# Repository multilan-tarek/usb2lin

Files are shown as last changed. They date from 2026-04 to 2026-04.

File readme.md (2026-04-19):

## USB2LIN

This is a 4-channel interface for LIN buses.\
It is using 4 NXP TJA1021 and a MaxLinear XR21V1414IM USB to UART bridge. 

Tested with BMW I/K-Bus, but it should work with any LIN bus.

---

### Gerber Files 
The gerber file is ready for ordering at JLCPCB.

### Parts
The schematic contains LCSC part numbers which can be exported to a BOM.

### Udev rules
This repository contains a udev rules file that maps the UART ports to ```/dev/lin/a@,b@,c@,d@```, matching the boards silkscreen.

---

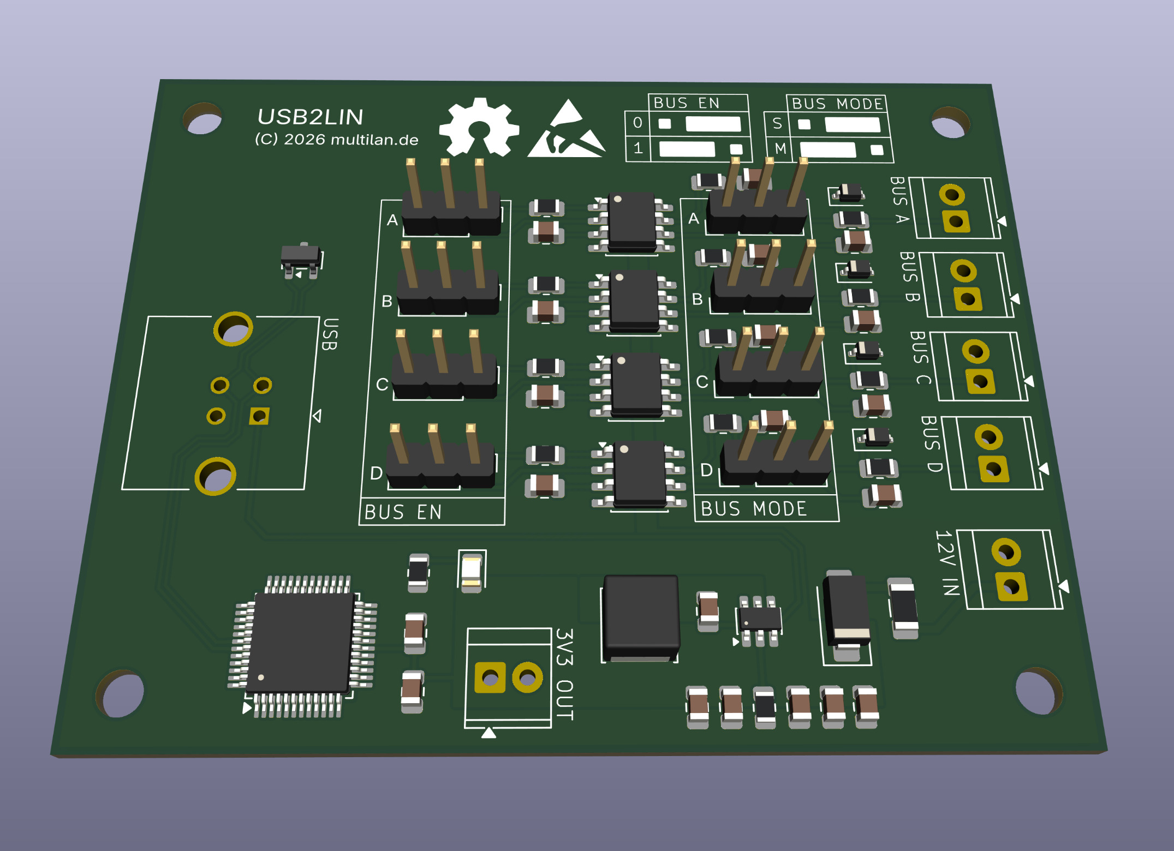
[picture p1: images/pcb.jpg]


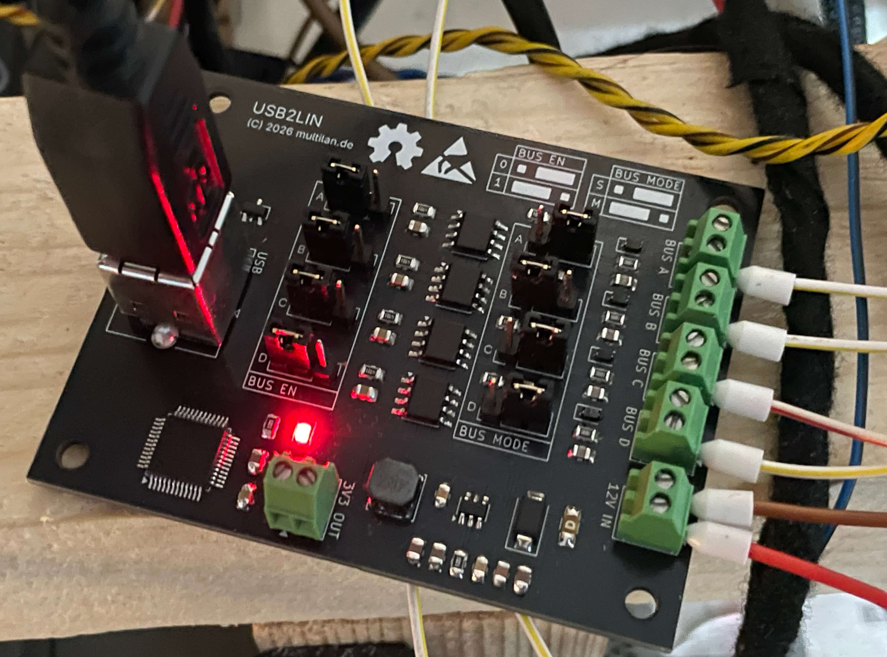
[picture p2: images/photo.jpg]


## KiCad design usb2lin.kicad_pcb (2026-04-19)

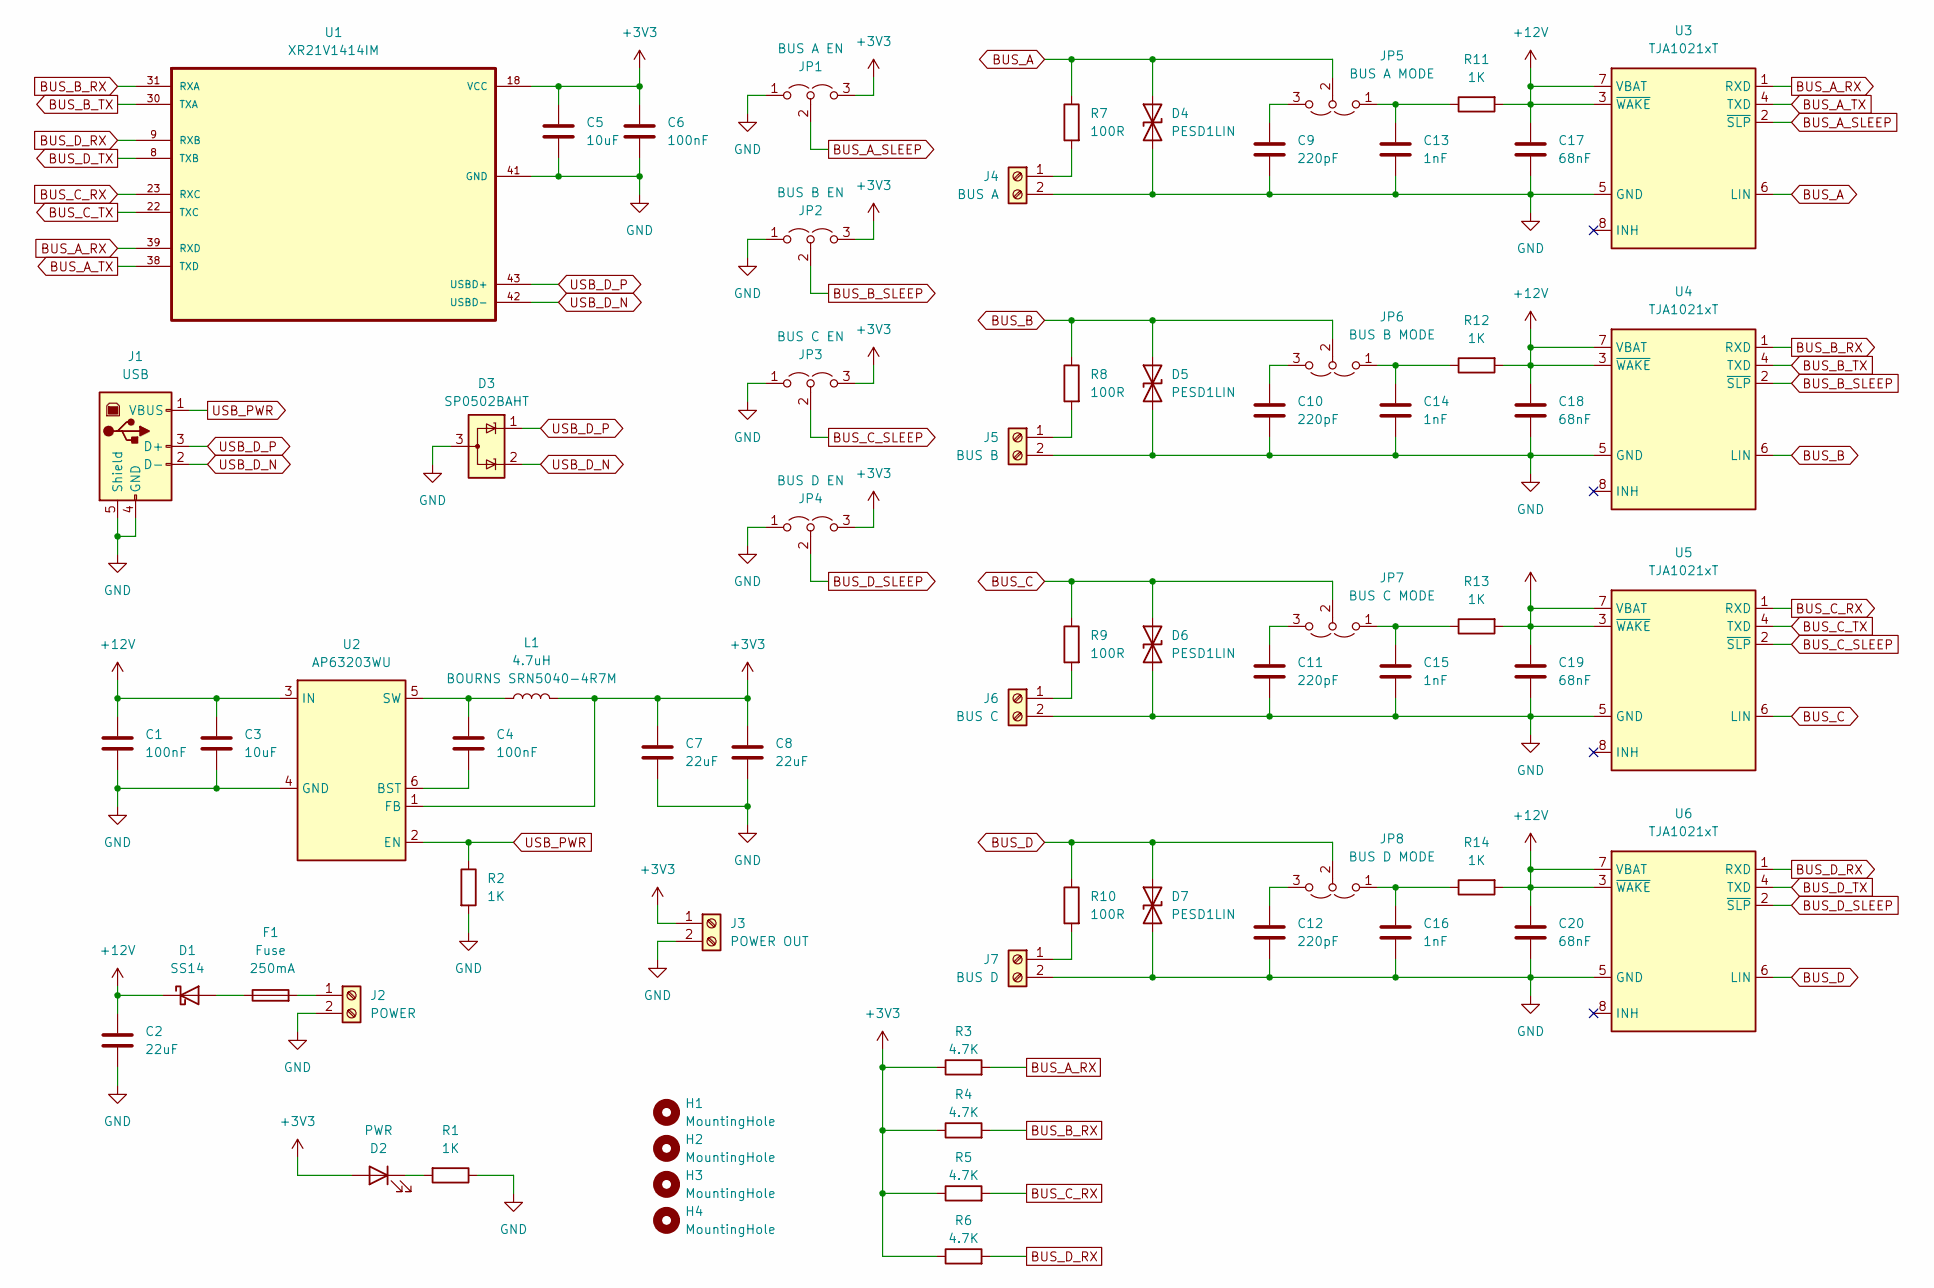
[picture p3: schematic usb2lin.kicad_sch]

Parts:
C1, C4, C6: 100nF; C_0805_2012Metric; LCSC C1711
C2, C7, C8: 22uF; C_0805_2012Metric; LCSC C602037
C3, C5: 10uF; C_0805_2012Metric; LCSC C15850
C9, C10, C11, C12: 220pF; C_0805_2012Metric; LCSC C472838
C13, C14, C15, C16: 1nF; C_0805_2012Metric; LCSC C46653
C17, C18, C19, C20: 68nF; C_0805_2012Metric; LCSC C472830
D1: SS14; D_SMA; LCSC C83852
D2: PWR; LED_0805_2012Metric; LCSC C94868
D3: SP0502BAHT; SOT-23; LCSC C207261
D4, D5, D6, D7: PESD1LIN; D_SOD-323; LCSC C58901
F1: Fuse; Fuse_1206_3216Metric_Pad1.42x1.75mm_HandSolder; LCSC C83557
H1, H2, H3, H4: MountingHole; MountingHole_3.2mm_M3
J1: USB; USB_B_TE_5787834_Vertical; LCSC C592900
J2: POWER; TerminalBlock_TE_282834-2_1x02_P2.54mm_Horizontal; LCSC C592983
J3: POWER OUT; TerminalBlock_TE_282834-2_1x02_P2.54mm_Horizontal; LCSC C592983
J4: BUS A; TerminalBlock_TE_282834-2_1x02_P2.54mm_Horizontal; LCSC C592983
J5: BUS B; TerminalBlock_TE_282834-2_1x02_P2.54mm_Horizontal; LCSC C592983
J6: BUS C; TerminalBlock_TE_282834-2_1x02_P2.54mm_Horizontal; LCSC C592983
J7: BUS D; TerminalBlock_TE_282834-2_1x02_P2.54mm_Horizontal; LCSC C592983
JP1: BUS A EN; PinHeader_1x03_P2.54mm_Vertical; LCSC C2937625
JP2: BUS B EN; PinHeader_1x03_P2.54mm_Vertical; LCSC C2937625
JP3: BUS C EN; PinHeader_1x03_P2.54mm_Vertical; LCSC C2937625
JP4: BUS D EN; PinHeader_1x03_P2.54mm_Vertical; LCSC C2937625
JP5: BUS A MODE; PinHeader_1x03_P2.54mm_Vertical; LCSC C2937625
JP6: BUS B MODE; PinHeader_1x03_P2.54mm_Vertical; LCSC C2937625
JP7: BUS C MODE; PinHeader_1x03_P2.54mm_Vertical; LCSC C2937625
JP8: BUS D MODE; PinHeader_1x03_P2.54mm_Vertical; LCSC C2937625
L1: 4.7uH; L_APV_ANR5040; LCSC C2041710
R1, R2, R11, R12, R13, R14: 1K; R_0805_2012Metric; LCSC C441981
R3, R4, R5, R6: 4.7K; R_0805_2012Metric; LCSC C336873
R7, R8, R9, R10: 100R; R_0805_2012Metric; LCSC C193990
U1: XR21V1414IM; TQFP-48_7x7mm_P0.5mm; MPN XR21V1414IM-0B-EB; LCSC C141719
U2: AP63203WU; TSOT-23-6; LCSC C780769
U3, U4, U5, U6: TJA1021xT; SOIC-8_3.9x4.9mm_P1.27mm; LCSC C182937

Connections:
+3V3: C5.1, C6.1, C7.1, C8.1, D2.2 (A), J3.1, JP1.3 (B), JP2.3 (B), JP3.3 (B), JP4.3 (B), L1.2, R3.1, R4.1, R5.1, R6.1, U1.5 (VCC), U1.18 (VCC), U1.33 (VCC), U1.44 (VCC), U1.45 (VCC), U2.1 (FB)
+12V: C1.1, C2.1, C3.1, C17.1, C18.1, C19.1, C20.1, D1.1 (K), R11.2, R12.2, R13.2, R14.2, U2.3 (IN), U3.3 (~WAKE), U3.7 (VBAT), U4.3 (~WAKE), U4.7 (VBAT), U5.3 (~WAKE), U5.7 (VBAT), U6.3 (~WAKE), U6.7 (VBAT)
BUS_A: D4.1 (A1), JP5.2 (C), R7.1, U3.6 (LIN)
BUS_A_RX: R3.2, U1.39 (RXD), U3.1 (RXD)
BUS_A_SLEEP: JP1.2 (C), U3.2 (~SLP)
BUS_A_TX: U1.38 (TXD), U3.4 (TXD)
BUS_B: D5.1 (A1), JP6.2 (C), R8.1, U4.6 (LIN)
BUS_B_RX: R4.2, U1.31 (RXA), U4.1 (RXD)
BUS_B_SLEEP: JP2.2 (C), U4.2 (~SLP)
BUS_B_TX: U1.30 (TXA), U4.4 (TXD)
BUS_C: D6.1 (A1), JP7.2 (C), R9.1, U5.6 (LIN)
BUS_C_RX: R5.2, U1.23 (RXC), U5.1 (RXD)
BUS_C_SLEEP: JP3.2 (C), U5.2 (~SLP)
BUS_C_TX: U1.22 (TXC), U5.4 (TXD)
BUS_D: D7.1 (A1), JP8.2 (C), R10.1, U6.6 (LIN)
BUS_D_RX: R6.2, U1.9 (RXB), U6.1 (RXD)
BUS_D_SLEEP: JP4.2 (C), U6.2 (~SLP)
BUS_D_TX: U1.8 (TXB), U6.4 (TXD)
GND: C1.2, C2.2, C3.2, C5.2, C6.2, C7.2, C8.2, C9.2, C10.2, C11.2, C12.2, C13.2, C14.2, C15.2, C16.2, C17.2, C18.2, C19.2, C20.2, D3.3 (A), D4.2 (A2), D5.2 (A2), D6.2 (A2), D7.2 (A2), J1.4 (GND), J1.5 (Shield), J2.2, J3.2, J4.2, J5.2, J6.2, J7.2, JP1.1 (A), JP2.1 (A), JP3.1 (A), JP4.1 (A), R1.1, R2.2, U1.1 (GND), U1.4 (GND), U1.19 (GND), U1.32 (GND), U1.40 (GND), U1.41 (GND), U2.4 (GND), U3.5 (GND), U4.5 (GND), U5.5 (GND), U6.5 (GND)
unnamed: D1.2 (A), F1.1
unnamed: D2.1 (K), R1.2
unnamed: F1.2, J2.1
unnamed: J4.1, R7.2
unnamed: J5.1, R8.2
unnamed: J6.1, R9.2
unnamed: J7.1, R10.2
unnamed: C13.1, JP5.1 (A), R11.1
unnamed: C9.1, JP5.3 (B)
unnamed: C14.1, JP6.1 (A), R12.1
unnamed: C10.1, JP6.3 (B)
unnamed: C15.1, JP7.1 (A), R13.1
unnamed: C11.1, JP7.3 (B)
unnamed: C16.1, JP8.1 (A), R14.1
unnamed: C12.1, JP8.3 (B)
unnamed: C4.2, U2.6 (BST)
unnamed: C4.1, L1.1, U2.5 (SW)
USB_D_N: D3.2 (K), J1.2 (D-), U1.42 (USBD-)
USB_D_P: D3.1 (K), J1.3 (D+), U1.43 (USBD+)
USB_PWR: J1.1 (VBUS), R2.1, U2.2 (EN)

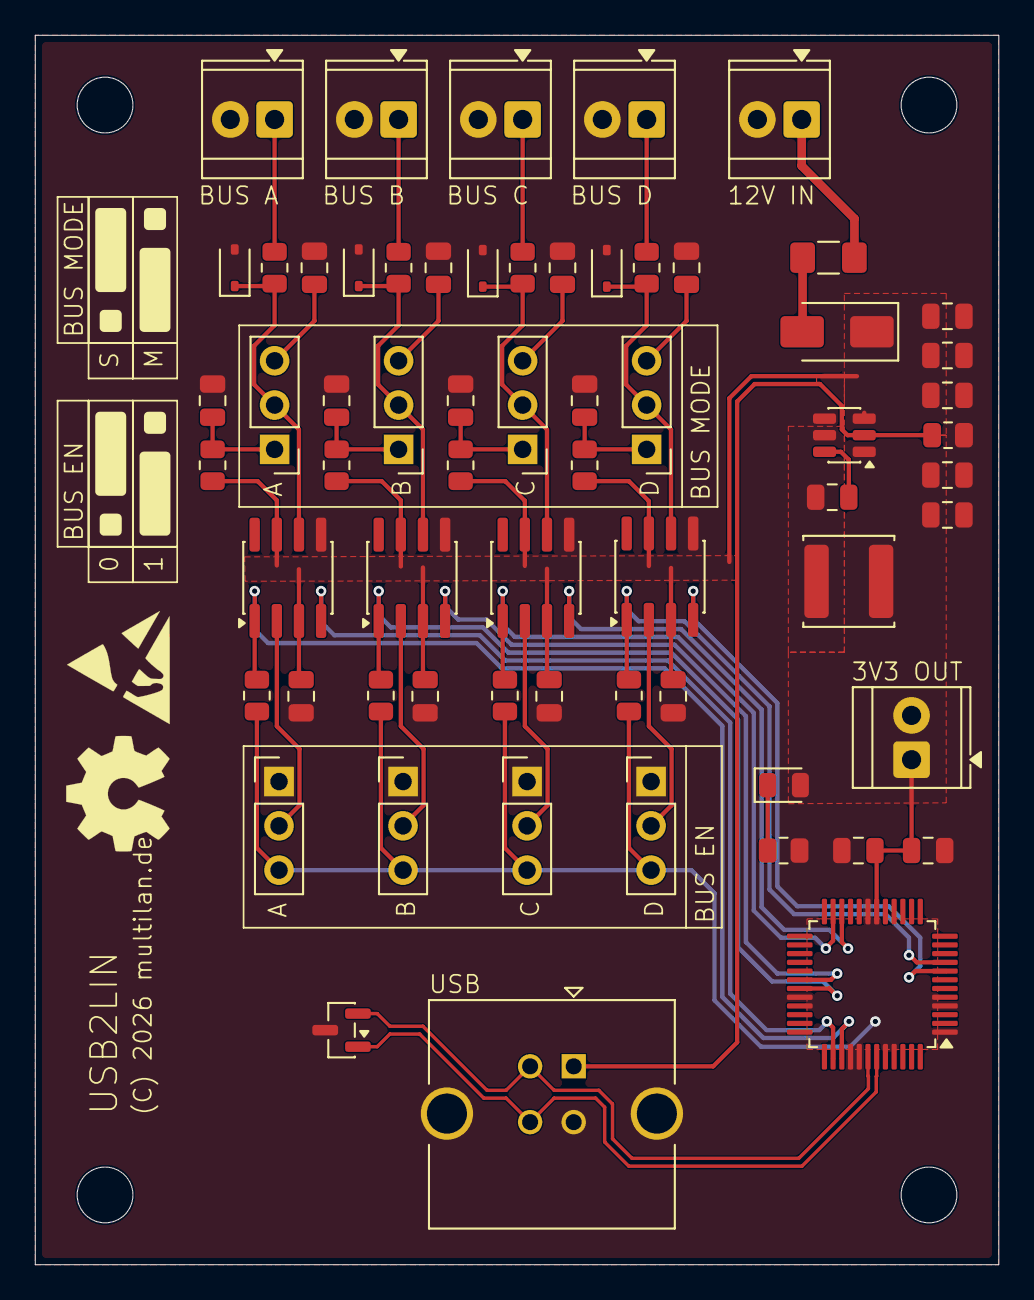
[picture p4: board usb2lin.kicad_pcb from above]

Board: 2 copper layers, 55.2 x 70.5 mm, 68 parts (0 on the bottom side), 39 nets.

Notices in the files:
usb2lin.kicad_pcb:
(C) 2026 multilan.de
